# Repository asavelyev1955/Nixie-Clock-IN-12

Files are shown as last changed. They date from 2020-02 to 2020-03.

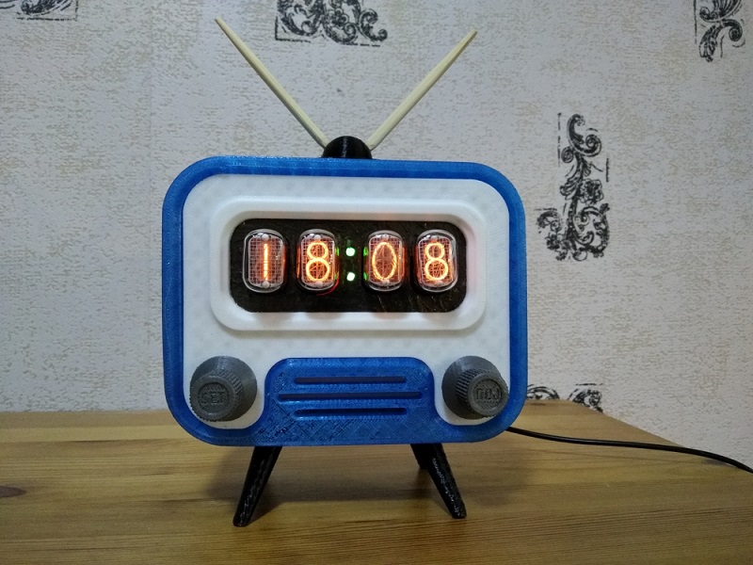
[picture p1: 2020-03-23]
IMG_20200229_180758_9.jpg

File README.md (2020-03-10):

# Nixie Clock IN-12, Arduino Nano, DS3231 modul & 155ИД1 с динамической индикацией
Шину +12V необходимо соединить перемычкой с выводом Vin Ардуино.
Спасибо Андрею Железнякову: https://itworkclub.ru/arduino-часы-на-газоразрядных-индикаторах/
Немного изменил исходную схему: вместо светодиодной точки поставил газоразрядную.
Stl файлы взяты отсюда: https://www.myminifactory.com/object/3d-print-nixie-funklock-vintage-tv-enclosure-99898

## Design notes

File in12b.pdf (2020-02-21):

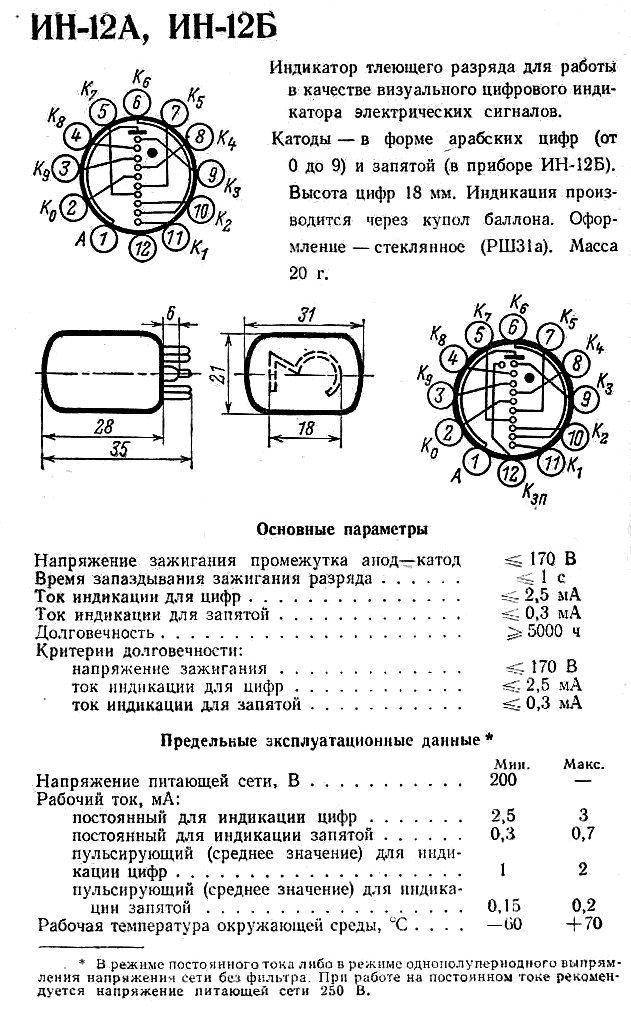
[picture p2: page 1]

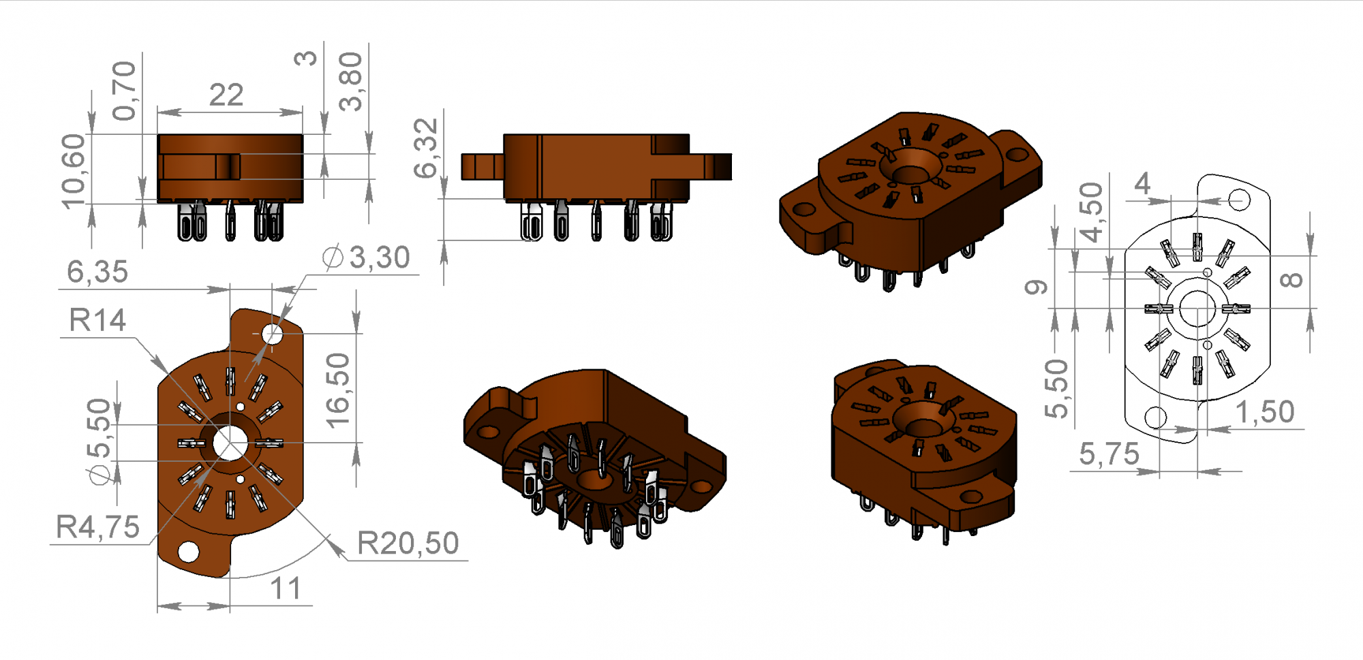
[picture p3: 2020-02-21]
IN12-socket.png

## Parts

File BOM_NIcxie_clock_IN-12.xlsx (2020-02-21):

ID | Name | Designator | Footprint | Quantity
1 | DISP_IN12A | DISP1,DISP2,DISP3,DISP4 | DISP_IN-12_SOCKET | 4
2 | Header-Male-2.54_1x10 | P3,P1 | HDR-10X1/2.54 | 2
3 | Header-Male-2.54_1x6 | P4,P2 | HDR-6X1/2.54 | 2
4 | IN-3 | N1 | IN-3 | 1
5 | DS3231 | CLOCK2 | DS3231 | 1
6 | ARDUINO-NANO-V3.0 | U6 | ARDUINO_NANO V3 | 1
7 | TLP627 | U7,U8,U9,U10,U1 | DIP4_MOD | 5
8 | 220µ | L2,L1 | AXIAL-27*8 | 2
9 | IRF840 | Q2 | TO-220_MOD | 1
10 | 4.7u 350В | C2 | CP_10X13MM | 1
11 | 22 | R7 | RC06 | 1
12 | 470 | R8,R1 | RC06 | 2
13 | 10k | R9,R11 | RC06 | 2
14 | К155ИД1 | DС2 | DIP16_MOD | 1
15 | keyboard | JP2 | 2PIN_MOD | 1
16 | 330k | R12 | RC06 | 1
17 | 100k | R2 | RC06 | 1
18 | 54819-0519 | CN1 | MINI_USB-0.8MM-5P-MOLEX-L9.0 | 1
19 | MT3608 | U21 | MT3608 | 1
20 | DC-005 | DC2 | DC-005B-13A | 1
21 | FR307 | D1 | DO-201AD | 1

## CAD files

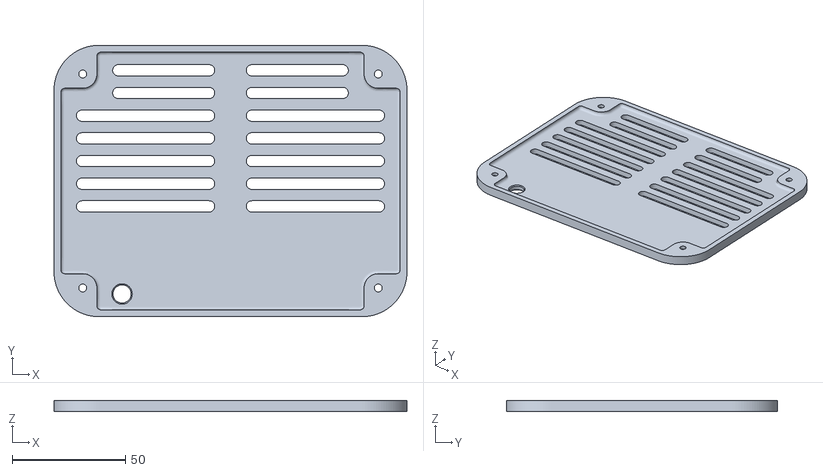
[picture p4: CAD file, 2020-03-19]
1x-back-lid-1.stl
155.6 x 119.6 x 5.00

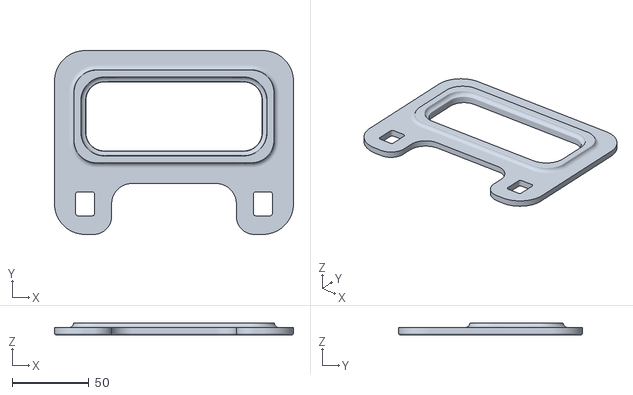
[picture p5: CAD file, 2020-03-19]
1x-front-lid.stl
156.0 x 120.0 x 8.00

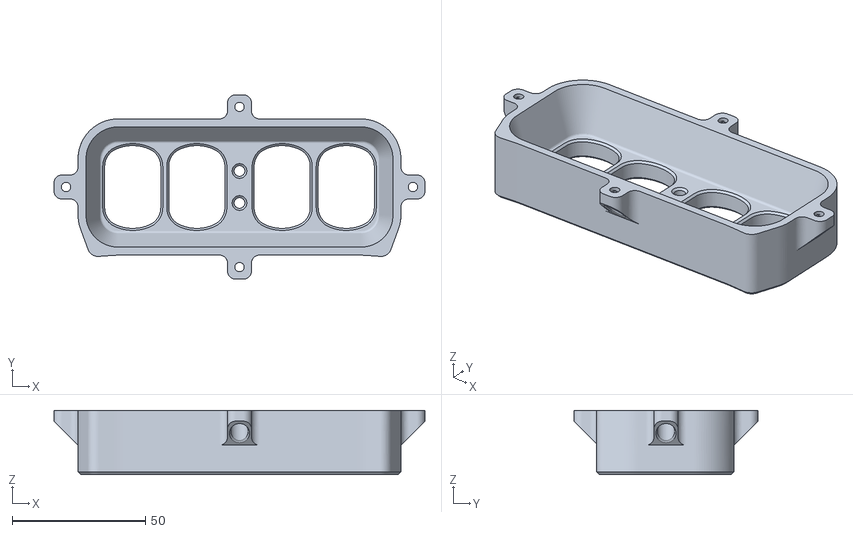
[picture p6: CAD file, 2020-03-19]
1x-clock-pcb-mount-cover.stl
139.0 x 69.0 x 24.0

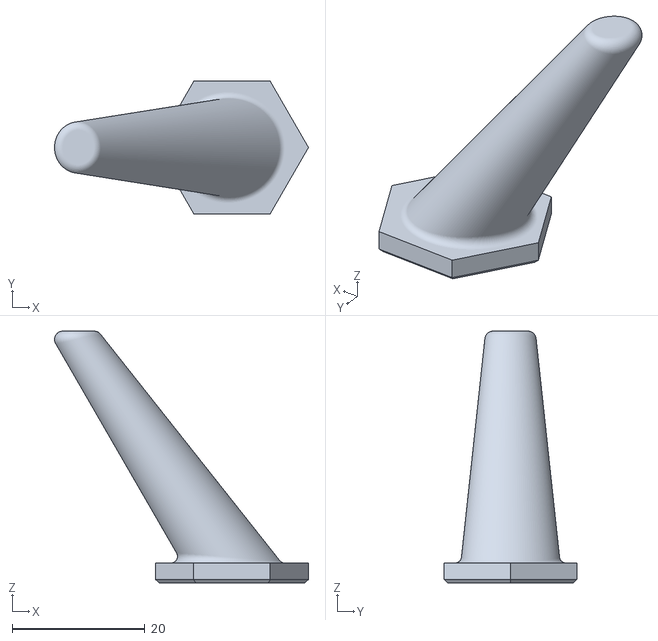
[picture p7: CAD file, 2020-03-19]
4x-feet.stl
38.3 x 20.0 x 38.0

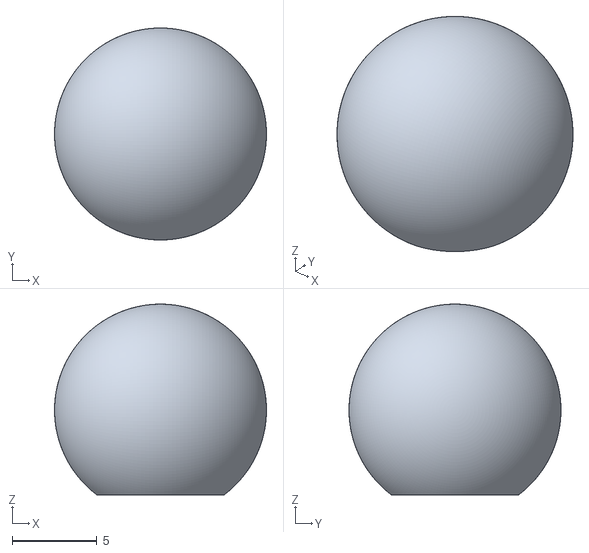
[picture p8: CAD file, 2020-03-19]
2x-dowel-cup.stl
12.5 x 12.5 x 11.2

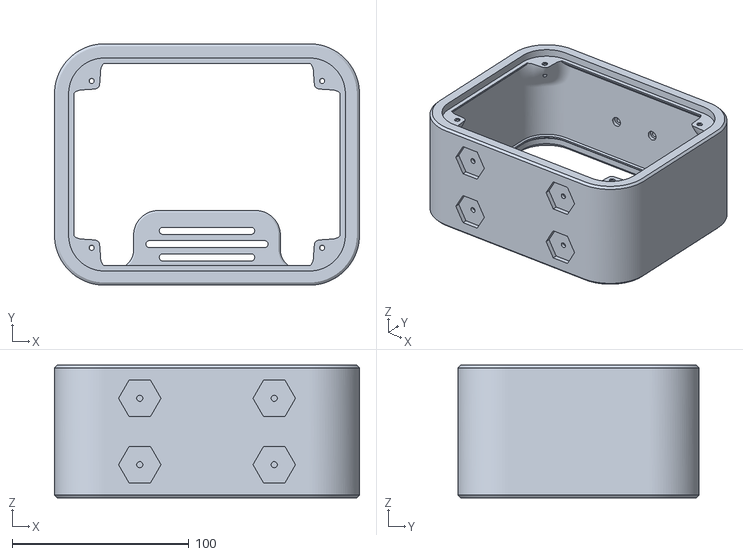
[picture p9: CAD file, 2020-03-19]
1x-body-1.stl
172.4 x 136.4 x 75.0

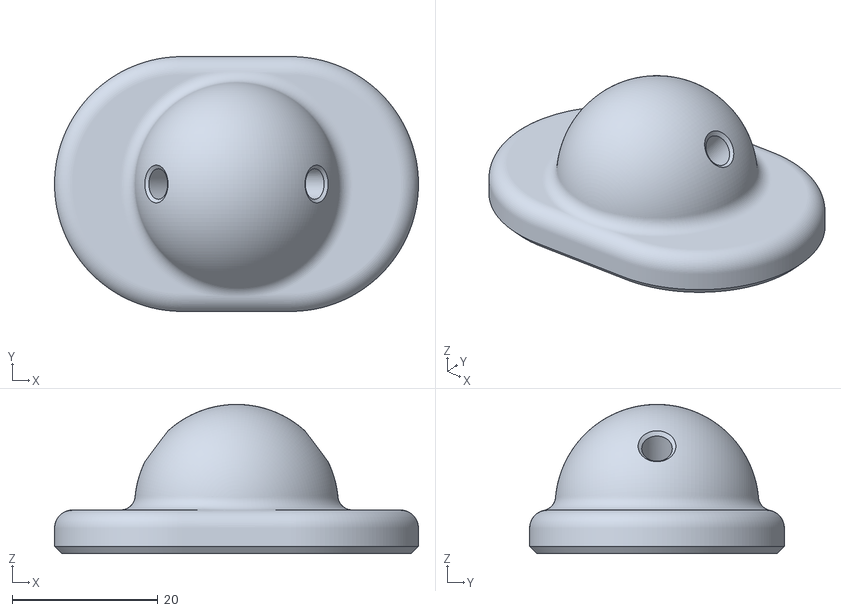
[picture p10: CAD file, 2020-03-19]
1x-antenna-mount.stl
50.0 x 35.0 x 20.5

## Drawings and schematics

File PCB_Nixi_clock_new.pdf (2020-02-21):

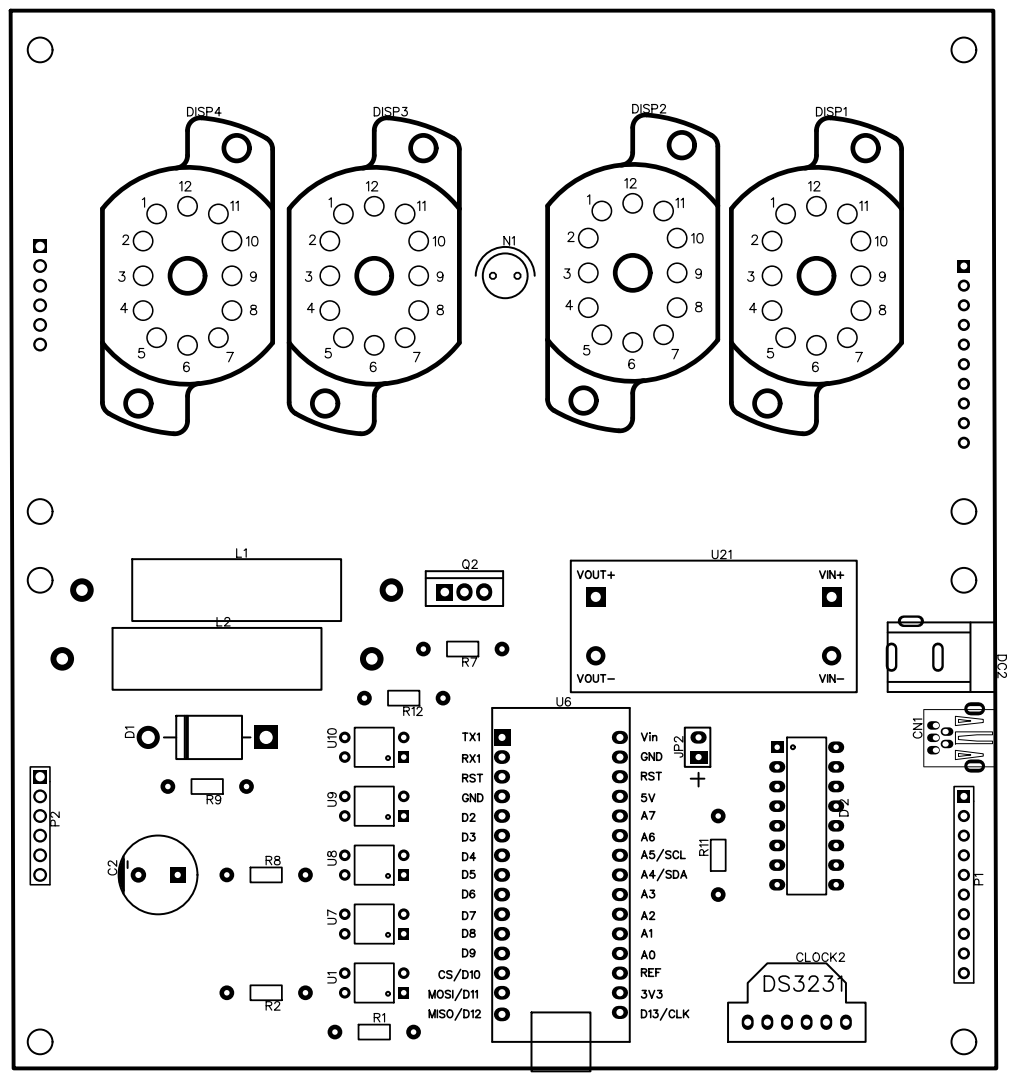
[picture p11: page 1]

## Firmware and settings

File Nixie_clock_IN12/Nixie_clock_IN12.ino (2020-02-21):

// схема Clock_IN-12 c Arduino Nano 155ИД1 и TLP627

#include <DS3231.h>
#include <Wire.h>
 
// выводы для дешифратора/катоды
  int out1 = A3;
  int out2 = A1;
  int out4 = A0;
  int out8 = A2;
// выводы для транзисторных ключей/аноды
  int key1 = 4;
  int key2 = 6;
  int key3 = 7;
  int key4 = 8;
 
  int led1=11;// вывод светодиода
  int keyb=A6;// пин для клавиатуры
 
 
  int keynum=0; //номер нажатой кнопки
  int mode =0; //0 - отображение текущего времени 1- установка времени
  int currentdigit = 0; //0 - установка часов 1- установка минут
  bool blinkflag = 0; // флаг для мигания цифр при установке времени
  bool timeout=false; // таймаут после нажатия кнопки (для устраниния дребезга)
  unsigned long startTime; //для мигания светодиода
  unsigned long startTime2; // для опроса нажатых кнопок
  int sec; //переменная увеличивается каждые 500мс на единицу. Нужна для мигания секундных светодиодов, 
  //бывает в двух значениях 0 - светодиоды не горят, 1 - горят, если больше 1, то сбрысывается в 0
 
  // переменные, необходимые для работы ds3231
  DS3231 Clock;
  bool Century=false;
  bool h12;
  bool PM;
  byte ADay, AHour, AMinute, ASecond, ABits;
  bool ADy, A12h, Apm;
 
  //определяем глобальные переменные для различных параметров часов
  int second,minute,hour,date,month,year,temperature;
  
  int lastMinute;
 
 
void setup() {
  
  // задаем частоту ШИМ на 9 выводе 30кГц
  TCCR1B=TCCR1B&0b11111000|0x01;
  
  analogWrite(9,130);
 
    // Start the I2C interface
  Wire.begin();
  // Start the serial interface
  Serial.begin(9600);
  
  //задаем режим работы выходов микроконтроллера
  pinMode(out1,OUTPUT);
  pinMode(out2,OUTPUT);
  pinMode(out4,OUTPUT);
  pinMode(out8,OUTPUT);
 
  pinMode(key1,OUTPUT);
  pinMode(key2,OUTPUT);
  pinMode(key3,OUTPUT);
  pinMode(key4,OUTPUT);
 
  pinMode(led1,OUTPUT);
 
  startTime = millis();
  startTime2=startTime;
  sec = 0;
  // считываем текущее вермя
  ReadDS3231();
  delay(1000);
  lastMinute = minute%10;
}
 
void ReadDS3231()   //функция считывает в глобальные переменные minute и hour текущие значения
{
  minute=Clock.getMinute();
  hour=Clock.getHour(h12, PM);
}
 
 
void loop() {
  // put your main code here, to run repeatedly:
  
  int digits[3]; // массив для текущего значения времени на четыре цифры
  int keyval= analogRead(keyb); // считываем значение с клавиатуры
  
  unsigned long currentTime = millis(); //текущее время с момента запуска рограммы
   if (currentTime>=(startTime2+200)) // если прошло 200мс посмотрим какая кнопка была нажата
   {
      timeout=false;
     //проверим нажатие кнопок
      if (keynum==3) // кнопка переключения между режимами "время" и "настройка"
      {
        timeout=true; // запрещаем считывать нажатия кнопок
        if (mode==0) mode=1; // если отображалось время, переходим в режим настроек
        else
          if (mode==1) mode=0; //если был режим настроек, переключаемся на текущее время
      }
      if (keynum==2) // кнопка переключения между часами и минутами
      {
        timeout=true; // запрещаем считывать нажатия кнопок
        // currentdigit либо 0 - настройка часов, либо 1 - настройка минут
        currentdigit++; 
        if (currentdigit==2) currentdigit=0;
      }
      if (keynum==1 && mode==1) // кнопка увеличения количества часов или минут(при настройке)
      {
        blinkflag=true; // прекращаем мигать цифрами
        startTime=millis();
        timeout=true;  // запрещаем считывать нажатия кнопок
        if (currentdigit==0) // если меняем часы
        {
          if (hour<=22) hour++;
          else
            hour=0;
          Clock.setHour(hour);
        }
        if (currentdigit==1) // если меняем минуты
        {
          if (minute<=58) minute++;
          else 
            minute=0;
         Clock.setMinute(minute);//Set the minute 
         Clock.setSecond(0);
        }
      }
      keynum=0; //сбрасываем нажатую кнопку
      startTime2=millis();
   }
 
  if (currentTime>=(startTime+500)) // если прошло 500мс
  {
    blinkflag=!blinkflag; // инвертируем флаг мигающей цифры
      
    if(sec<1) // светодиоды не горят
    {
      // зажечь светодиоды
      digitalWrite(led1,HIGH);
      Serial.println(blinkflag);
      Serial.print("Keyval=");
      Serial.println(keyval);
      
    }
    if(sec>=1) // светодиоды горят
    {
      // потушить светодиоды
      digitalWrite(led1,LOW);
    }
    startTime = currentTime;
    ReadDS3231(); 
    sec = (sec+1);
    if(sec>=2) sec=0;
 
  }
    digits[0] = hour/10;
    digits[1] = hour%10;
    digits[2] = minute/10;
    digits[3] = minute%10;
  
    //антиотравление
  if (minute%10!=lastMinute && mode == 0)
  {

    digits[3] = lastMinute;
    lastMinute = minute%10;
    
    Safe(digits);
    digits[3] = lastMinute;
  }
  //
 
    show(digits); // вывести цифры на дисплей
 
  //проверяем нажатые кнопки
  if(!timeout) //если разрешено, считываем нажатую кнопку
  {
    /*keyval - значение функции analogread 
     * если нажата первая кнопка, то принимает значение около 200
     * если нажата вторая кнопка то значение около 700
     * если третяя кнопка, то значение будет около 1000
     * эти значения зависят от выбранных резисторов в клавиатуре
    */
    if (keyval>150 && keyval<400) keynum=1;
    if (keyval>700 && keyval<900) keynum=2;
    if (keyval>960) keynum=3;
  }
}
void show(int a[])
{
    //выведем цифру a[0] на первый индикатор
  setNumber(a[0]);
  if (!(mode==1&&currentdigit==0&&blinkflag==false)) //если мы в режиме настройки и происходит 
  //настройка часов, то в первая цифра будет мигать
  {
    digitalWrite(key1,HIGH);
    delay(2);
    //потушим первый индикатор
    digitalWrite(key1,LOW);
    delay(1);
  }
  
  //цифра a[1] на второй индикатор
  setNumber(a[1]);
  if (!(mode==1&&currentdigit==0&&blinkflag==false))
  {
  digitalWrite(key2,HIGH);
  delay(2);
  //потушим второй индикатор
  digitalWrite(key2,LOW);
  delay(1);
  }
 
  //цифра a[2] на третий индикатор
  setNumber(a[2]);
  if (!(mode==1&&currentdigit==1&&blinkflag==false))
  {
  digitalWrite(key3,HIGH);
  delay(2);
  //потушим третий индикатор
  digitalWrite(key3,LOW);
  delay(1);
  }
 
  //выведем цифру a[3] на четвертый индикатор
  setNumber(a[3]);
  if (!(mode==1&&currentdigit==1&&blinkflag==false))
  {
  digitalWrite(key4,HIGH);
  delay(2);
  //потушим четвертый индикатор
  digitalWrite(key4,LOW);
  delay(1);
  }
}
// передача цифры на дешифратор
void setNumber(int num) 
{
  switch (num)
  {
    case 0:
    digitalWrite (out1,LOW);
    digitalWrite (out2,LOW);
    digitalWrite (out4,LOW);
    digitalWrite (out8,LOW);
    break;
    case 1:
    digitalWrite (out1,HIGH);
    digitalWrite (out2,LOW);
    digitalWrite (out4,LOW);
    digitalWrite (out8,LOW);
    break;
    case 2:
    digitalWrite (out1,LOW);
    digitalWrite (out2,HIGH);
    digitalWrite (out4,LOW);
    digitalWrite (out8,LOW);
    break;
    case 3:
    digitalWrite (out1,HIGH);
    digitalWrite (out2,HIGH);
    digitalWrite (out4,LOW);
    digitalWrite (out8,LOW);
    break;
    case 4:
    digitalWrite (out1,LOW);
    digitalWrite (out2,LOW);
    digitalWrite (out4,HIGH);
    digitalWrite (out8,LOW);
    break;
    case 5:
    digitalWrite (out1,HIGH);
    digitalWrite (out2,LOW);
    digitalWrite (out4,HIGH);
    digitalWrite (out8,LOW);
    break;
    case 6:
    digitalWrite (out1,LOW);
    digitalWrite (out2,HIGH);
    digitalWrite (out4,HIGH);
    digitalWrite (out8,LOW);
    break;
    case 7:
    digitalWrite (out1,HIGH);
    digitalWrite (out2,HIGH);
    digitalWrite (out4,HIGH);
    digitalWrite (out8,LOW);
    break;
    case 8:
    digitalWrite (out1,LOW);
    digitalWrite (out2,LOW);
    digitalWrite (out4,LOW);
    digitalWrite (out8,HIGH);
    break;
    case 9:
    digitalWrite (out1,HIGH);
    digitalWrite (out2,LOW);
    digitalWrite (out4,LOW);
    digitalWrite (out8,HIGH);
    break;
  }
}
void Safe(int n[])
{
  int h1 = n[0];
  int h2 = n[1];
  int m1 = n[2];
  int m2 = n[3];

  n[0]++;
  while(n[0]!=h1)
  {
    
    for (int x=0;x<2;x++)
    {
      show(n);
    }
    n[0]++;
    if (n[0]>9) n[0]=0;
  }
  
  n[1]++;
  while(n[1]!=h2)
  {
    
    for (int x=0;x<2;x++)
    {
      show(n);
    }
    n[1]++;
    if (n[1]>9) n[1]=0;
  }
  
  n[2]++;
  while(n[2]!=m1)
  {
    
    for (int x=0;x<2;x++)
    {
      show(n);
    }
    n[2]++;
    if (n[2]>9) n[2]=0;
  }
  
  n[3]++;
  while(n[3]!=m2)
  {
    
    for (int x=0;x<2;x++)
    {
      show(n);
    }
    n[3]++;
    if (n[3]>9) n[3]=0;
  }
  

}

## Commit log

2020-03-19 3DSmax file - подпорка
2020-03-23 фото
2020-04-13 Схема
